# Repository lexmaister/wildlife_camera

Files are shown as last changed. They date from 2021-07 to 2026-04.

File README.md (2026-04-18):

# Wildlife camera

Wildlife camera project based on Raspberry Pi Zero W with 5Mp Camera and PIR motion sensor.

## Raspberry Pi Zero W setup

### Flasing RPi OS

The most straight way to prepare SD-card is ising `rpi-imager`. It can be installed with:

```sh
sudo apt install rpi-imager
```

Due to Zero Pi will used with battery power source and without display, it is more efficient to use Raspberry Pi OS Lite:

* Text-only operating system.
* No graphical desktop, fewer background processes.
* Consumes less power, boots faster, less load on CPU and RAM.

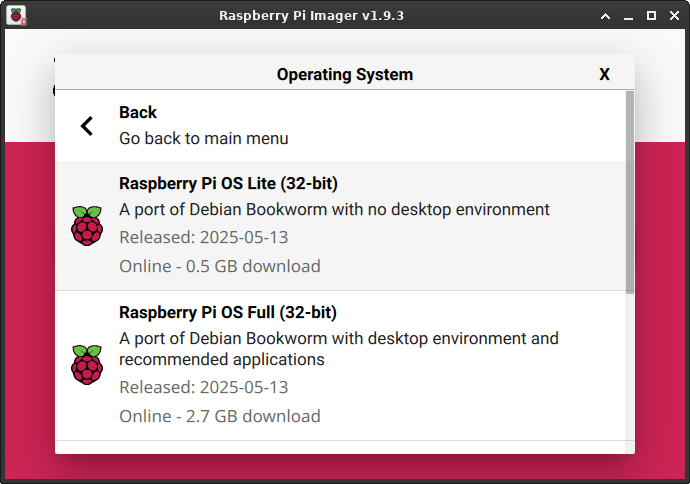
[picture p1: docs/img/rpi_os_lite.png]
rpi_os_lite


Using `rpi-imager` allows to initially set up our system to use `ssh` and put credentials to connect to wi-fi network after first boot, so board will be accessible via ssh:

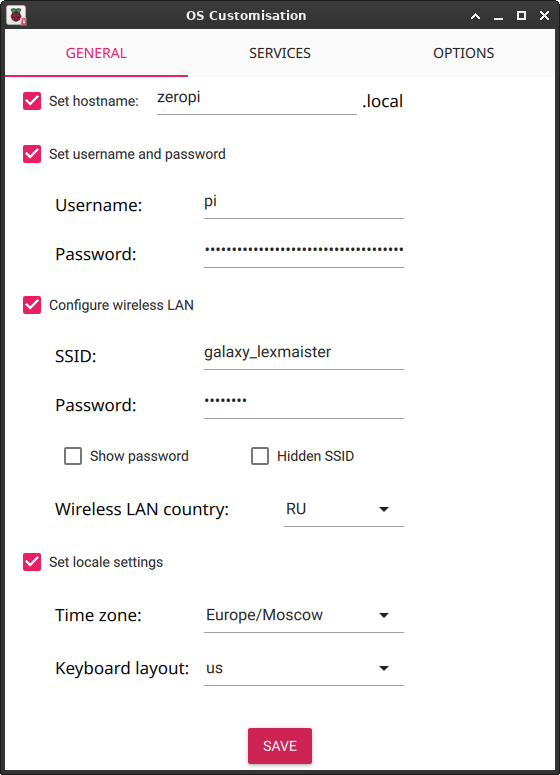
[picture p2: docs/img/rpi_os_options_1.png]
settings_1


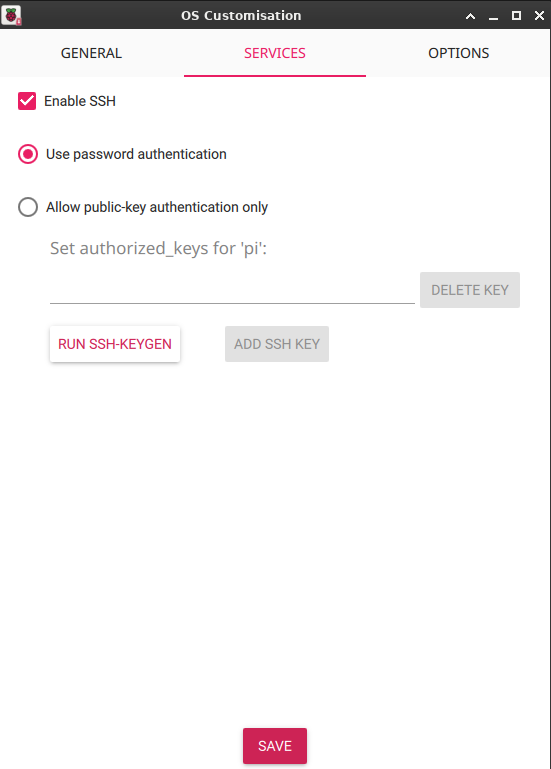
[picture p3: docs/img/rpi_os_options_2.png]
settings_2


### Connect to board - setup USB gadget

After flashing, insert your SD card to Zero Pi and wait for about 1 minute while it's booting. You also can check router info to wait until Zero Pi connects to it.

Then it should be accessible to connect to with ssh:

```sh
ssh pi@zeropi.local
```

Then you can setup USB-gadget mode to connect with terminal.
In Zero Pi console:

```sh
echo "dtoverlay=dwc2" | sudo tee -a /boot/firmware/config.txt 
echo " modules-load=dwc2,g_serial" | sudo tee -a /boot/firmware/cmdline.txt
# reboot
sudo reboot
```

After reboot - check if serial device is available

```sh
ls /dev/ttyGS0
sudo systemctl is-active getty@ttyGS0.service
```

Now you can connect to Zero Pi via USB cable (plug it into `USB` connector on board) with terminal utility such as `picocom`:

```sh
# check which serial device is used on your machine
sudo dmesg | grep tty
# example output: [ 4719.975580] cdc_acm 3-1:2.0: ttyACM0: USB ACM device
picocom /dev/ttyACM0 -b 115200
```

### Setup and check camera

For using as wildlife camera it is nessesary to turn of the camera led (in Zero Pi console):

```sh
echo "disable_camera_led=1" | sudo tee -a /boot/firmware/config.txt 
```

Then check if camera can grab images on full resolution with [built-in camera software](https://www.raspberrypi.com/documentation/computers/camera_software.html)

```sh
# available cameras
rpicam-still --list-cameras
```

output should be like:

```sh
Available cameras
-----------------
0 : ov5647 [2592x1944 10-bit GBRG] (/base/soc/i2c0mux/i2c@1/ov5647@36)
    Modes: 'SGBRG10_CSI2P' : 640x480 [58.92 fps - (16, 0)/2560x1920 crop]
                             1296x972 [46.34 fps - (0, 0)/2592x1944 crop]
                             1920x1080 [32.81 fps - (348, 434)/1928x1080 crop]
                             2592x1944 [15.63 fps - (0, 0)/2592x1944 crop]
```

Get full resolution test image:

```sh
rpicam-still -n --width 2592 -o test.jpg
```

Test image should appear in `/home/pi` directory.

<!-- Previously you shold install `vlc` and codecs and streaming:
```sh
sudo apt update
sudo apt install vlc-bin ffmpeg
``` -->

Next test - 5 seconds video clip with FullHD resolution:

```sh
rpicam-vid -n -t 5s --width 1980 --height 1080 -o test.h264
```

Copy this files to your PC and check if they were recorded properly. To watch `.h264` video you can use:

```sh
ffplay test.h264
```

## Setup video streaming

[TCP streaming](https://www.raspberrypi.com/documentation/computers/camera_software.html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) will be used for pointing and aiming the camera.

### Uncapsulated H264

Zero Pi as server:

```sh
rpicam-vid -t 0 -n --inline --listen -o tcp://0.0.0.0:8888
```

On client side - to view video:

```sh
ffplay tcp://zeropi.local:8888 -vf "setpts=N/((25)*TB)" -fflags nobuffer -flags low_delay -framedrop
```

### MPEG

Run server:

```sh
rpicam-vid -t 0 -n --codec mjpeg --listen -o tcp://0.0.0.0:8888
```

On client side - PC `VLC`:

```sh
vlc tcp/mjpeg://<ZEROPI_IP_ADDRESS>:8888
```

On Android with `VLC`:

* Open `VLC`
* Add new stream: `tcp://<ZEROPI_IP_ADDRESS>:8888`

## PIR sensor

[Comprehensive guide](https://learn.adafruit.com/pir-passive-infrared-proximity-motion-sensor/overview) to PIR sensor work principles, design and usage. Sensor settings for this project:

* the jumper is in the `H position`,
* `time` is minimal,
* `sensetivity` is medium.

### Connect to Zero Pi

To connect PIR sensor to Zero Pi we'll use the `J8` connector:

![j8header-zero](./docs/img/j8header-zero.png)

Sensor should be connected to the following pins:

* 1 - `3.3 VDC`
* 9 - `Ground`
* 11 - `GPIO 17` - sensor's `Out` signal

## System setup

Install libraries and git:

```sh
sudo apt update
sudo apt install python3-picamera2 --no-install-recommends
sudo apt install git
```

Clone project from GitHub:

```sh
git clone git clone https://github.com/lexmaister/wildlife_camera.git
cd wildlife_camera/scripts/ 
```

Then make the scripts executable:

```sh
chmod +x *.sh *.py
```

Now you can check if PIR-sensor is working - run script and move a palm ahead of it:

```sh
./pir_check.py
```

If it works, script should print `Motion detected!` and then close.

## Start capturing

Run script to start video streaming, connect to the camera with `vlc` and point it:

```sh
./lv_stream.sh
```

After aiming, run capturing with command (options are available):

```sh
./rwc_start.py

usage: rwc_start.py [-h] [-m MODE] [-d N]

Capture wonderful moments of life in the wild nature with Raspberry Pi
Wildlife Camera

options:
  -h, --help            show this help message and exit
  -m MODE, --mode MODE  Capture mode [snapshot, clip], default: clip
  -d N, --duration N    Clip duration in seconds, default: 10
```

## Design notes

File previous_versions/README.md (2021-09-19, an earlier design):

# wildlife_camera

Project to create Wild Life camera with Orange Pi PC plus / Raspberry Pi Zero W

Stage 1 - first revision with Orange Pi PC Plus and A4Tech PK-130MJ
* [description in my blog](https://lets-go-design-with-lexmaister.blogspot.com/2021/07/wildlife-camera.html)

Stage 2 - timelapse camera based on Raspberry Pi Zero W and RPi Cam 5Mp
* [description in my blog](https://lets-go-design-with-lexmaister.blogspot.com/2021/09/wildlife-camera-raspberry-pi-zero-w.html)

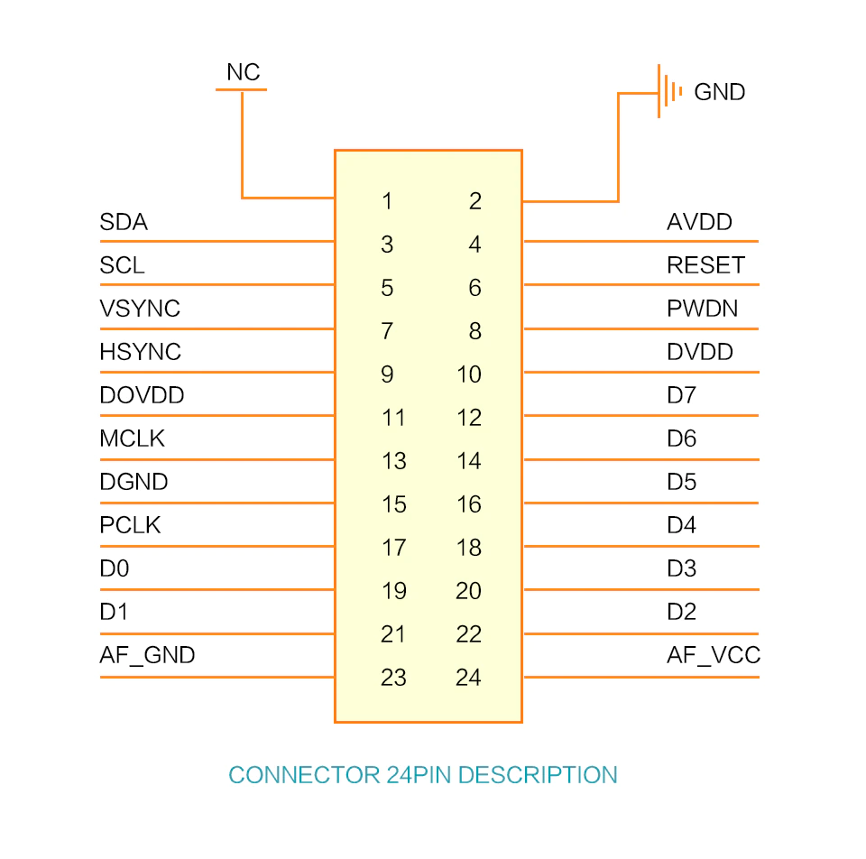
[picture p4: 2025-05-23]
docs/5Mp_CSI_cam_schematic.webp

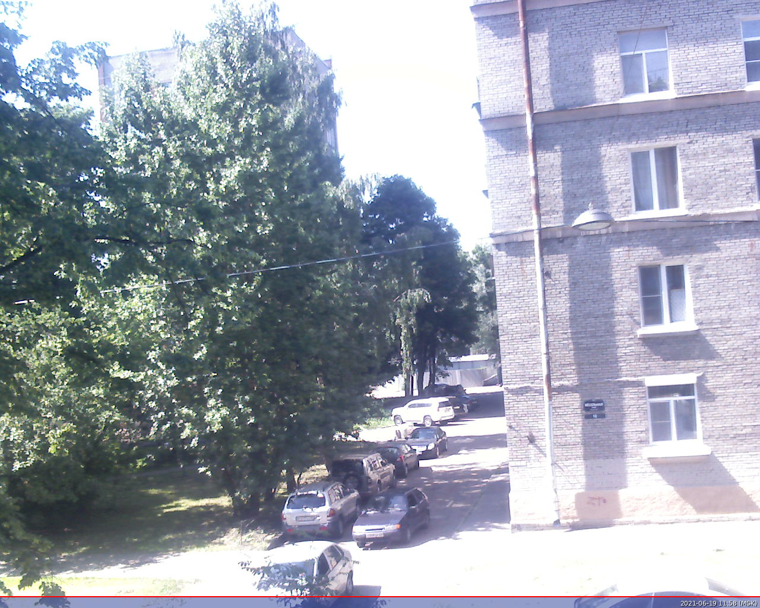
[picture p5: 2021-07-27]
S1. Wildlife camera - Orange Pi PC Plus/images/img_2021-06-19_11:58:48.jpg

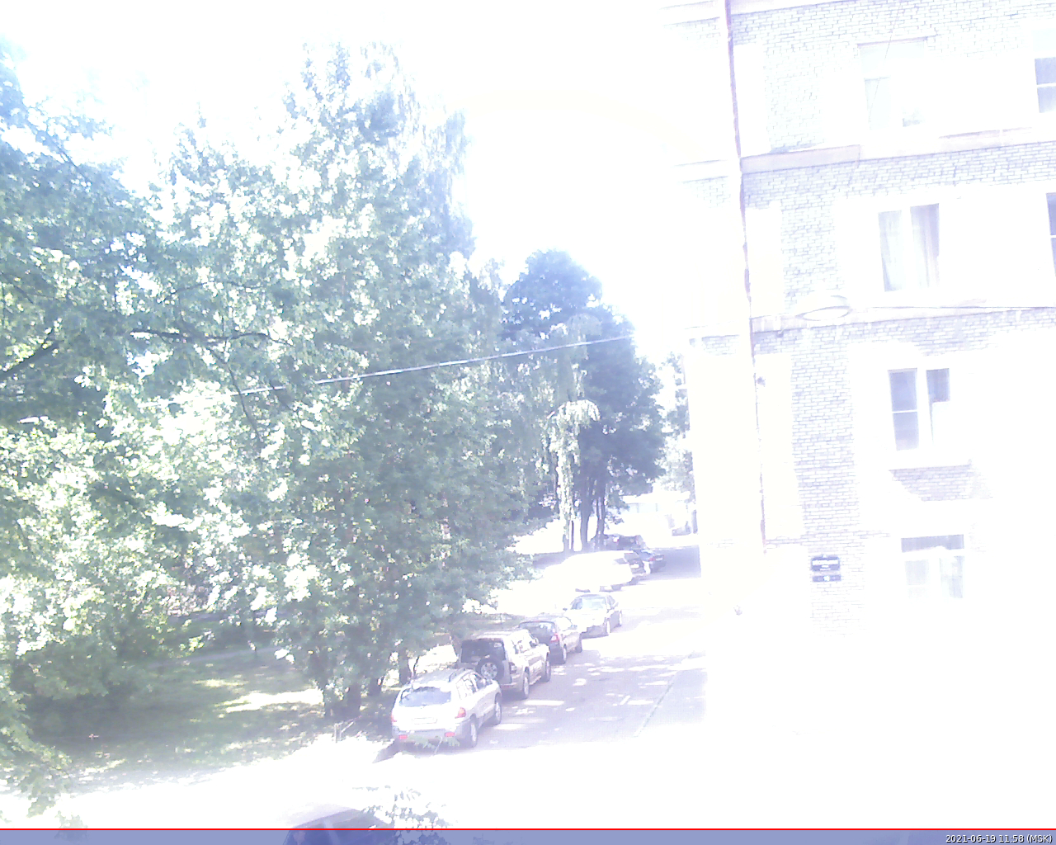
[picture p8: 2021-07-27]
S1. Wildlife camera - Orange Pi PC Plus/images/img_2021-06-19_11:58:58.jpg

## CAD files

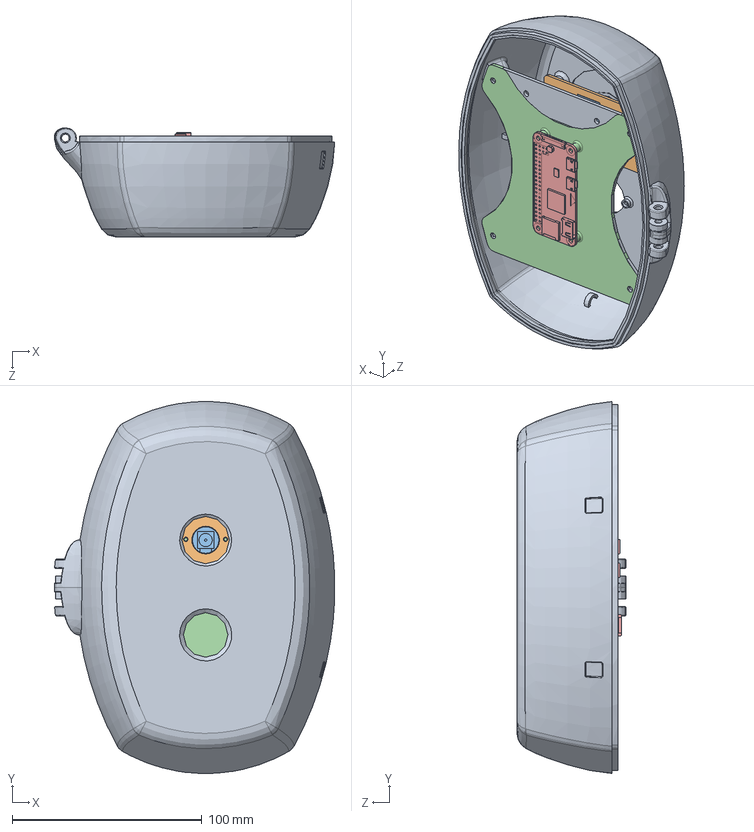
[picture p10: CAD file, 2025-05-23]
model/solidworks/Assy.SLDASM
147.9 x 196.1 x 57.5 mm
Основание
pi_camera_plate
RPi cam Rev 1.3
zero_pi_w_plate
RaspberryPiZeroW

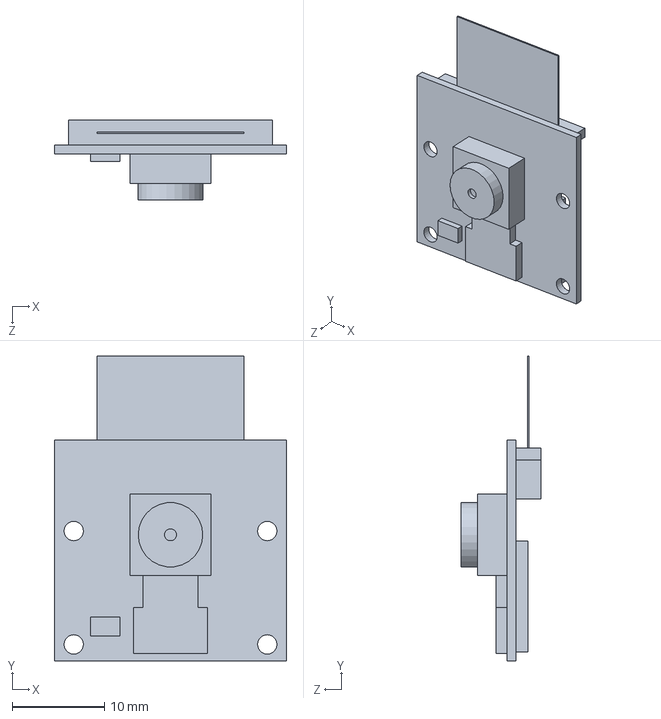
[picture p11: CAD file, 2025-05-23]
model/solidworks/RPi cam Rev 1.3.SLDPRT
25.2 x 33.1 x 8.70 mm

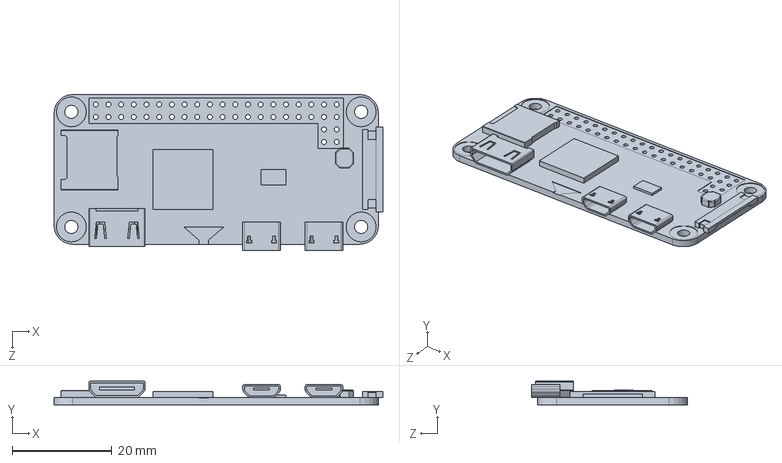
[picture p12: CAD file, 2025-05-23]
model/solidworks/RaspberryPiZeroW.SLDPRT
65.9 x 4.80 x 31.2 mm

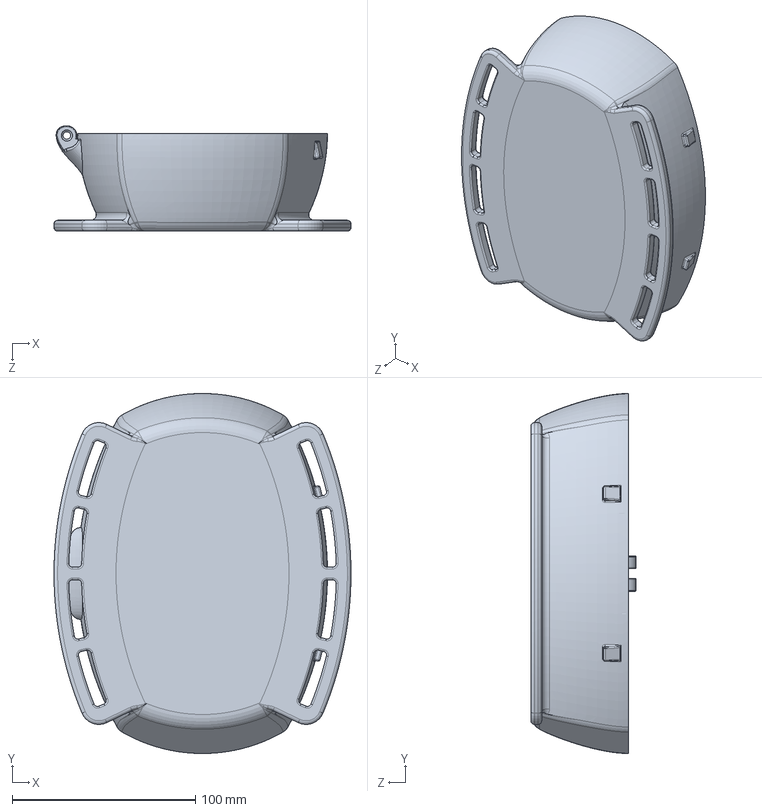
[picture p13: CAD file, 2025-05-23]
model/solidworks/Крышка.SLDPRT
162.0 x 196.4 x 57.5 mm

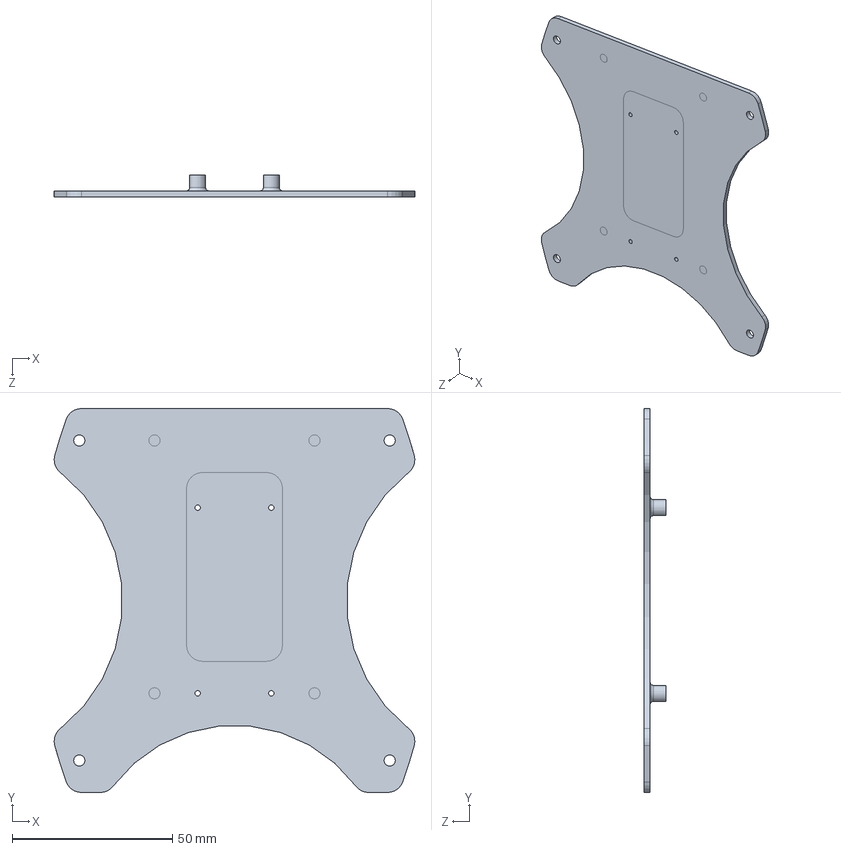
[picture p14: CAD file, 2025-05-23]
model/solidworks/zero_pi_w_plate.sldprt
112.7 x 120.0 x 7.01 mm

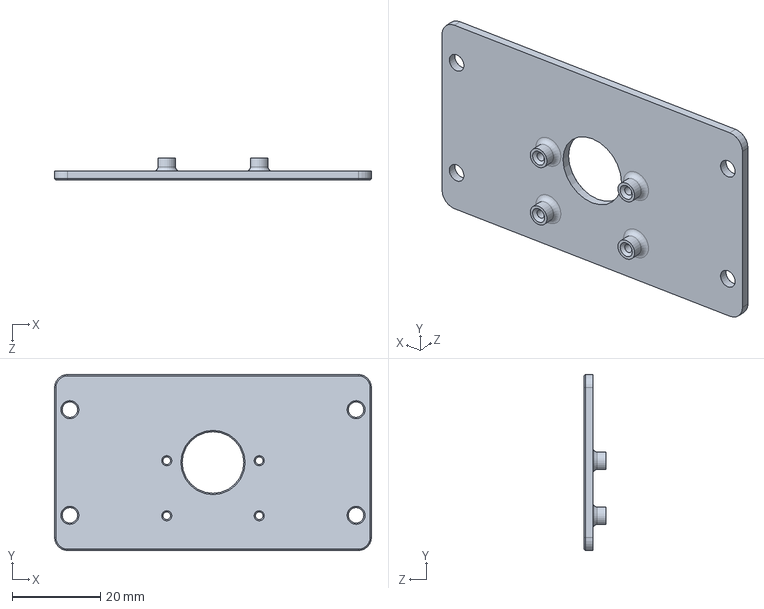
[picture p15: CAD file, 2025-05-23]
model/solidworks/pi_camera_plate.SLDPRT
72.0 x 40.0 x 5.00 mm

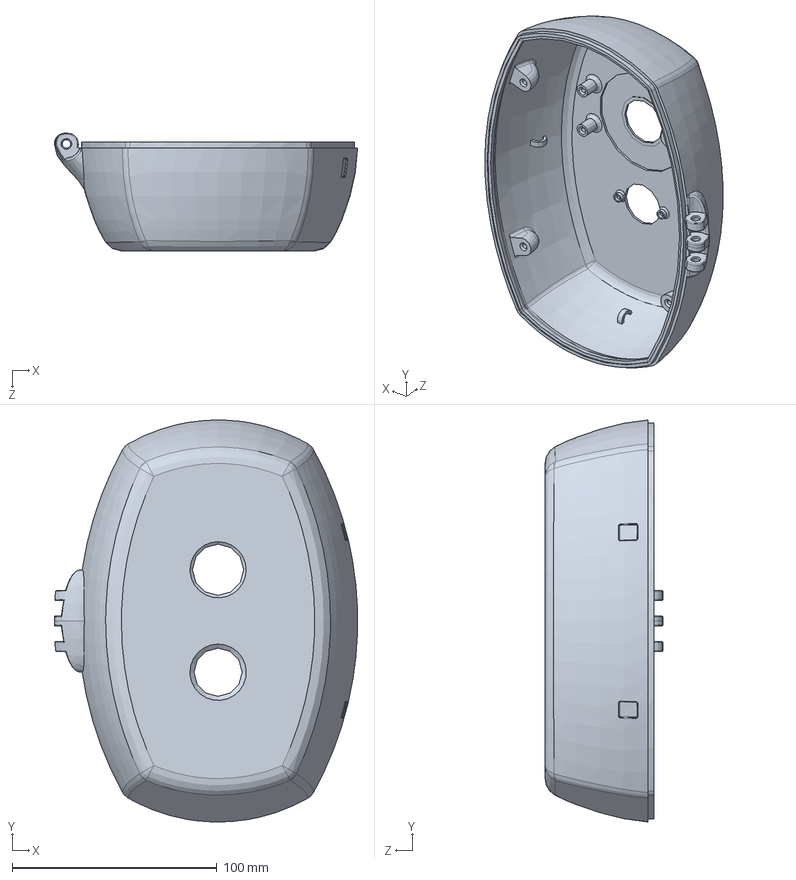
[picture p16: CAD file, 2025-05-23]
model/solidworks/Основание.SLDPRT
147.9 x 196.1 x 57.5 mm

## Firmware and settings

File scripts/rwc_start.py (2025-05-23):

#!/usr/bin/env python3
"""
The script to provide Raspberry Wildlife Camera functionality
"""
print('Starting Raspberry Pi Wildlife Camera...')
import os
from time import sleep
from datetime import datetime as dt
import argparse
from gpiozero import MotionSensor
from picamera2 import Picamera2
from picamera2.encoders import H264Encoder, Quality


SNAPSHOT = 'snapshot'
CLIP = 'clip'


class RWC:
    '''Class Raspberry Pi Wildlife Camera'''
    def __init__(self, mode: str, clip_duration: int):
        '''Init a Raspberry Pi Wildlife Camera class instance:
        
        Parameters:
            * mode(str): capture mode: snapshot or clip
            * clip_duration(int): desired video clip duration in seconds
        '''
        self.mode = mode
        self.clip_dur = clip_duration
        self.session_dir = self.make_session_dir()
        
        self.cam = Picamera2()
        if mode == SNAPSHOT:
            config = self.cam.create_still_configuration({"size": (2592,1944)})
        elif mode == CLIP:
            main = {'size': (1920, 1080), 'format': 'YUV420'}
            controls = {'FrameRate': 30}
            config = self.cam.create_video_configuration(main, controls=controls)

        self.cam.configure(config)
        self.cam.start(show_preview=False)
        sleep(1)
        print('---> Camera is configured')

        self.pir = MotionSensor(
            pin=17, 
            queue_len=1, 
            sample_rate=1
        )
        print('---> PIR-sensor is configured on GPIO_17 pin')

    def make_session_dir(self) -> str:
        '''Create a directory to save grabbed images / clips
        
        Returns:
            * absolute path to session directory
        '''
        script_dir = os.path.dirname(__file__)
        img_dir = os.path.join(script_dir, '../img')
        if not os.path.exists(img_dir):
            os.mkdir(img_dir)

        dt_start = dt.now().strftime('%Y-%m-%d_%H.%M.%S')
        session_dir = os.path.join(img_dir, dt_start)
        if not os.path.exists(session_dir):
            os.mkdir(session_dir)

        print(f'---> Session directory: {session_dir}')
        return session_dir

    def get_free_space(self) -> int:
        '''Calculate free space in session directory
        
        Returns:
            * available space in megabytes
        '''
        stat = os.statvfs(self.session_dir)
        free_mb = (stat.f_bavail * stat.f_frsize) / 1024 / 1024
        print(f'---> Available space: {free_mb:.1f} Mb')
        return free_mb

    def snapshot(self):
        '''Take a snapshot and save to current session directory'''
        print('---> Taking snapshot...')
        fn = f"img_{dt.now()}.jpg"
        self.cam.capture_file(os.path.join(self.session_dir, fn))
        print(f'---> Shapshot is saved: {fn!r}')

    def clip(self):
        '''Take a clip and save to current session directory'''
        print(f'---> Taking clip {self.clip_dur} s...')
        fn = f"img_{dt.now()}.h264"
        self.cam.start_recording(
            H264Encoder(), 
            os.path.join(self.session_dir, fn),
            quality=Quality.VERY_HIGH
            )
        sleep(self.clip_dur + 1) # added 1s for init
        self.cam.stop_recording()
        print(f'---> Clip is saved: {fn!r}')
    
    def run(self):
        '''Start the main loop'''
        while True:
            if self.pir.value > 0:
                if self.mode == SNAPSHOT:
                    self.snapshot()
                else:
                    self.clip()

                if self.get_free_space() < 100:
                    print('!!! STOP - not enough space to proceed grabbing !!!')
                    break
            else:
                sleep(1)
    

if __name__ == '__main__':
    parser = argparse.ArgumentParser(
        prog='rwc_start.py',
        description='Capture wonderful moments of life in the wild nature with Raspberry Pi Wildlife Camera',
        add_help=True
        )
    parser.add_argument(
        '-m', '--mode', 
        choices=[SNAPSHOT, CLIP], 
        default=CLIP,
        type=str,
        help='Capture mode [snapshot, clip], default: clip',
        metavar='MODE'
        )
    parser.add_argument(
        '-d', '--duration', 
        default=10,
        type=int,
        help='Clip duration in seconds, default: 10',
        metavar='N'
        )

    args = parser.parse_args()
    mode = args.mode
    clip_dur = args.duration
    print(f'---> Start with parameters: mode = {mode!r}, clip duration = {clip_dur}')

    rwc = RWC(mode=mode, clip_duration=clip_dur)
    rwc.run()

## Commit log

2021-07-27 S1. Wildlife camera - Orange Pi PC Plus
2025-05-23 feat: working rwc_start main script + 3d model + readme draft
    [Assy.SLDASM, RPi cam Rev 1.3.SLDPRT, RaspberryPiZeroW.SLDPRT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]
2025-05-23 feat: set framerate 30 explicitly, keep 1s for init when camera starts
2026-04-23 refactor: switch to use libcamera-still instead of raspistill
